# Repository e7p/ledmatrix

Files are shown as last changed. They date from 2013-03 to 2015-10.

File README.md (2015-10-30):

ledmatrix
=========

We got a couple of LED matrices in our Hackerspace /dev/tal in Wuppertal. Here there is held code and other useful things for them.

Important info: The Fusebit for "JTAG" MUST be deactivated for usage of PORT C, which is used by default for serial data!

How to build
------------

To build the Firmware, just enter the directory "main" and type `make`. For flashing the firmware `make flash` can be used, or the main.hex file can be flashed using an arbitrary AVR flashing tool.

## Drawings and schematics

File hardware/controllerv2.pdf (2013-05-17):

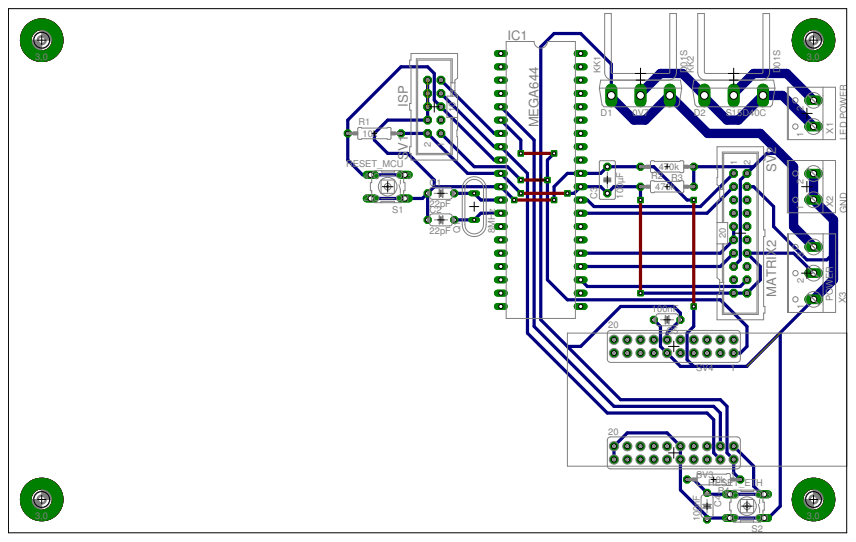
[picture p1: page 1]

10 21 12 20 1 20 1 20 1 2 1 2 1 2 3 2 1 4 3 2 1 4 3 IC1 Q1 C1 C2 C3 R1 SV1 SV2 X3 R2 R3 SV3 SV4 S1 S2 R4C4 C5 D1 D2 X1 X2 KK1 KK2 MEGA644 8MHz 22pF 22pF 100µF 10k ISP MATRIX2 POWER 470k R 470k ESET_MCU R1E0kSET_ETH 100nF 100nF 0V7 S15D40C LED POWER GND D01S D01S3,0 3,0 3,0 3,0

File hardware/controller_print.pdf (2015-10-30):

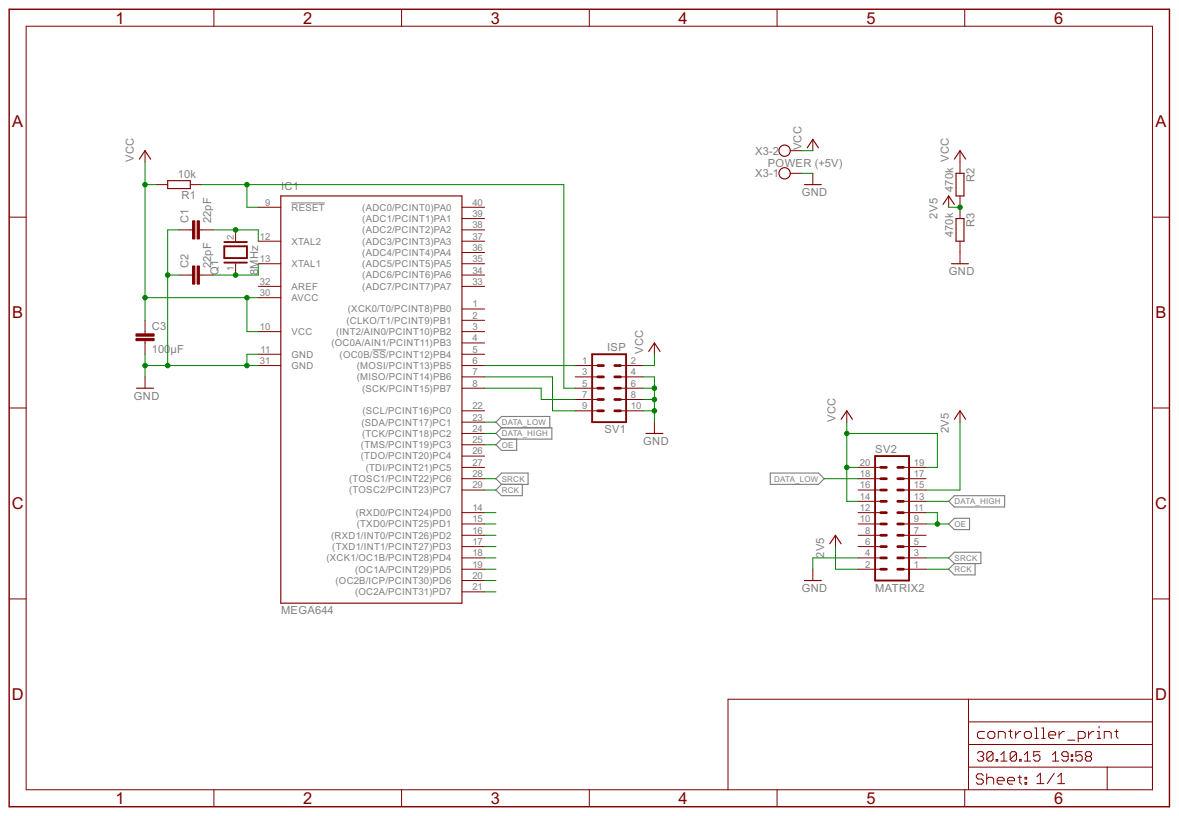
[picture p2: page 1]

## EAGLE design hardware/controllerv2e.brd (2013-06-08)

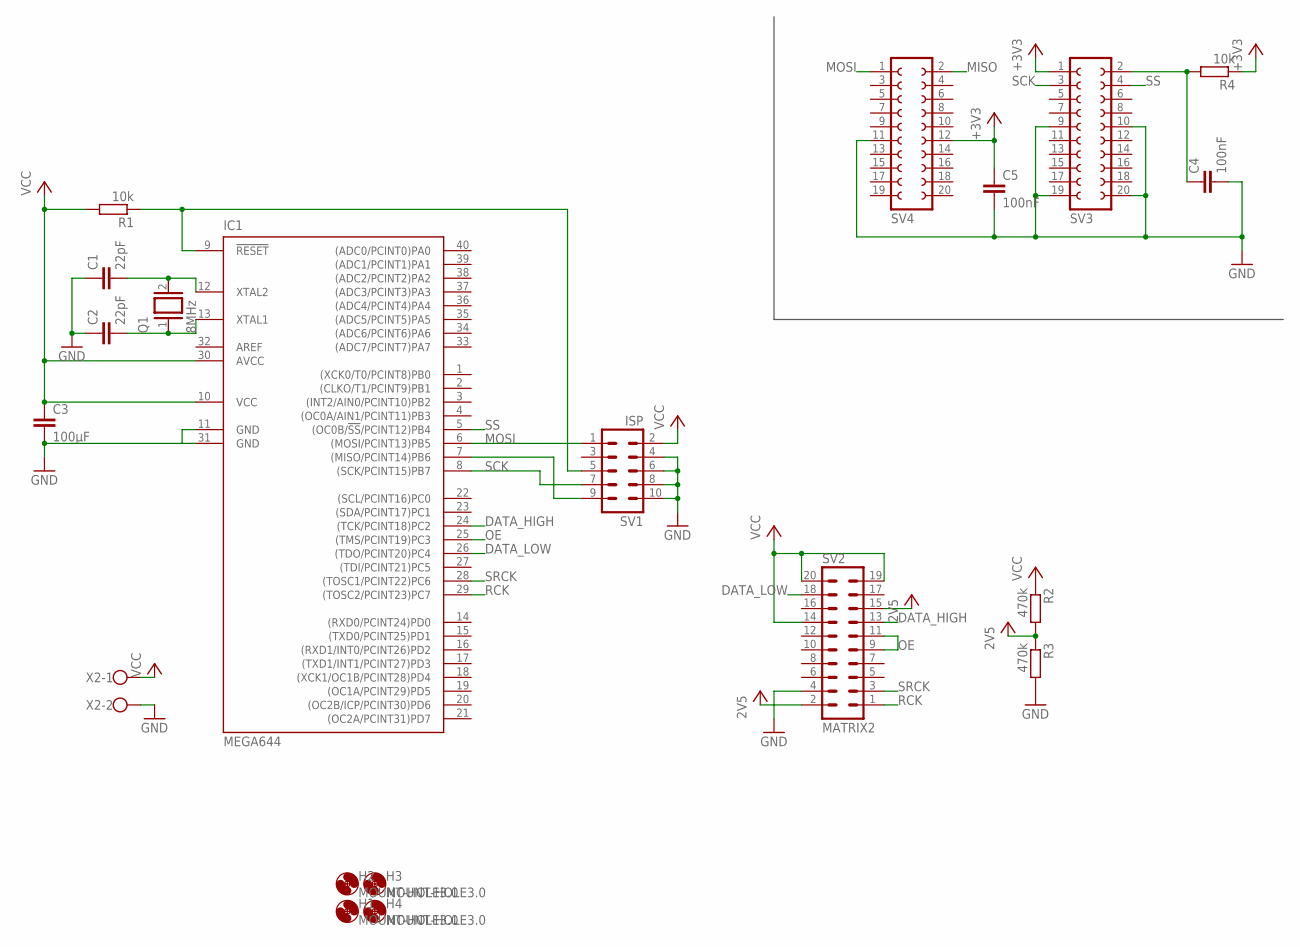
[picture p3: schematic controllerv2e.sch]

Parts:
C1, C2: 22pF; C050-024X044
C3: 100µF; C050-030X075
C4, C5: 100nF; C050-024X044
H1, H2, H3, H4: MOUNT-HOLE3.0; 3,0
IC1: MEGA644; DIL40
Q1: 8MHz; QS
R1, R4: 10k; 0207/10
R2, R3: 470k; 0207/10
SV1: ISP; ML10
SV2: MATRIX2; ML20
SV3, SV4: FE10-2
X2: GND; W237-102

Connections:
+3V3: C5.1, R2.2, R3.1, R4.1, SV2.2, SV2.15, SV3.1, SV4.12
AREF: IC1.32 (AREF)
DATA_HIGH: IC1.24 ((TCK/PCINT18)PC2), SV2.13
DATA_LOW: IC1.26 ((TDO/PCINT20)PC4), SV2.18
GND: C1.1, C2.1, C3.2, C4.2, C5.2, IC1.11 (GND), IC1.31 (GND), R3.2, SV1.4, SV1.6, SV1.8, SV1.10, SV2.4, SV3.9, SV3.10, SV3.19, SV3.20, SV4.11, X2.2
MISO: SV4.2
MOSI: IC1.6 ((MOSI/PCINT13)PB5), SV1.1, SV4.1
unnamed: C4.1, R4.2, SV3.2
unnamed: C2.2, IC1.13 (XTAL1), Q1.1
unnamed: C1.2, IC1.12 (XTAL2), Q1.2
unnamed: IC1.9 (!RESET), R1.1, SV1.5
unnamed: IC1.7 ((MISO/PCINT14)PB6), SV1.9
OE: IC1.25 ((TMS/PCINT19)PC3), SV2.9, SV2.11
RCK: IC1.29 ((TOSC2/PCINT23)PC7), SV2.1
SCK: IC1.8 ((SCK/PCINT15)PB7), SV1.7, SV3.3
SRCK: IC1.28 ((TOSC1/PCINT22)PC6), SV2.3
SS: IC1.5 ((OC0B/!SS!/PCINT12)PB4), SV3.4
VCC: C3.1, IC1.10 (VCC), IC1.30 (AVCC), R1.2, R2.1, SV1.2, SV2.14, SV2.19, SV2.20, X2.1

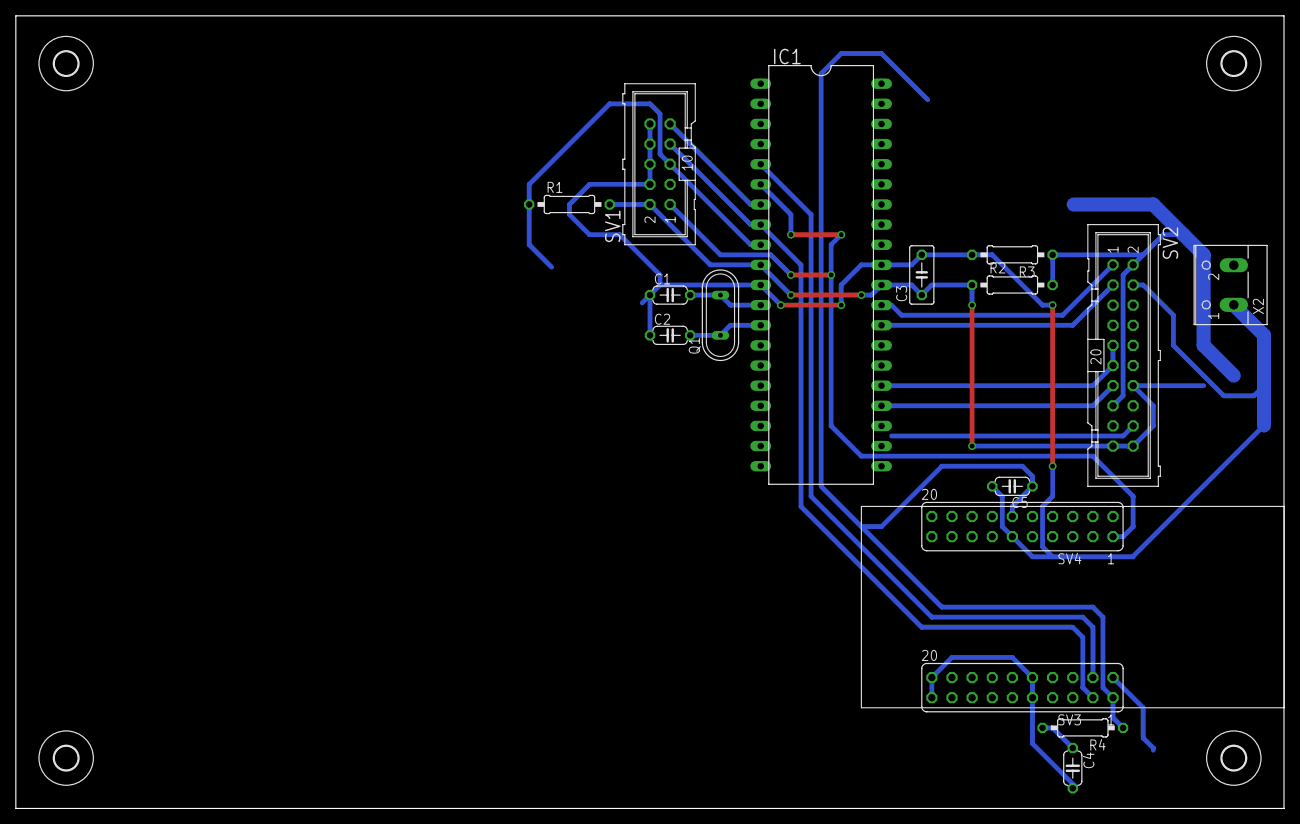
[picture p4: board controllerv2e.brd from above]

Board: 2 copper layers, 160.0 x 100.0 mm, 20 parts (0 on the bottom side), 16 nets.

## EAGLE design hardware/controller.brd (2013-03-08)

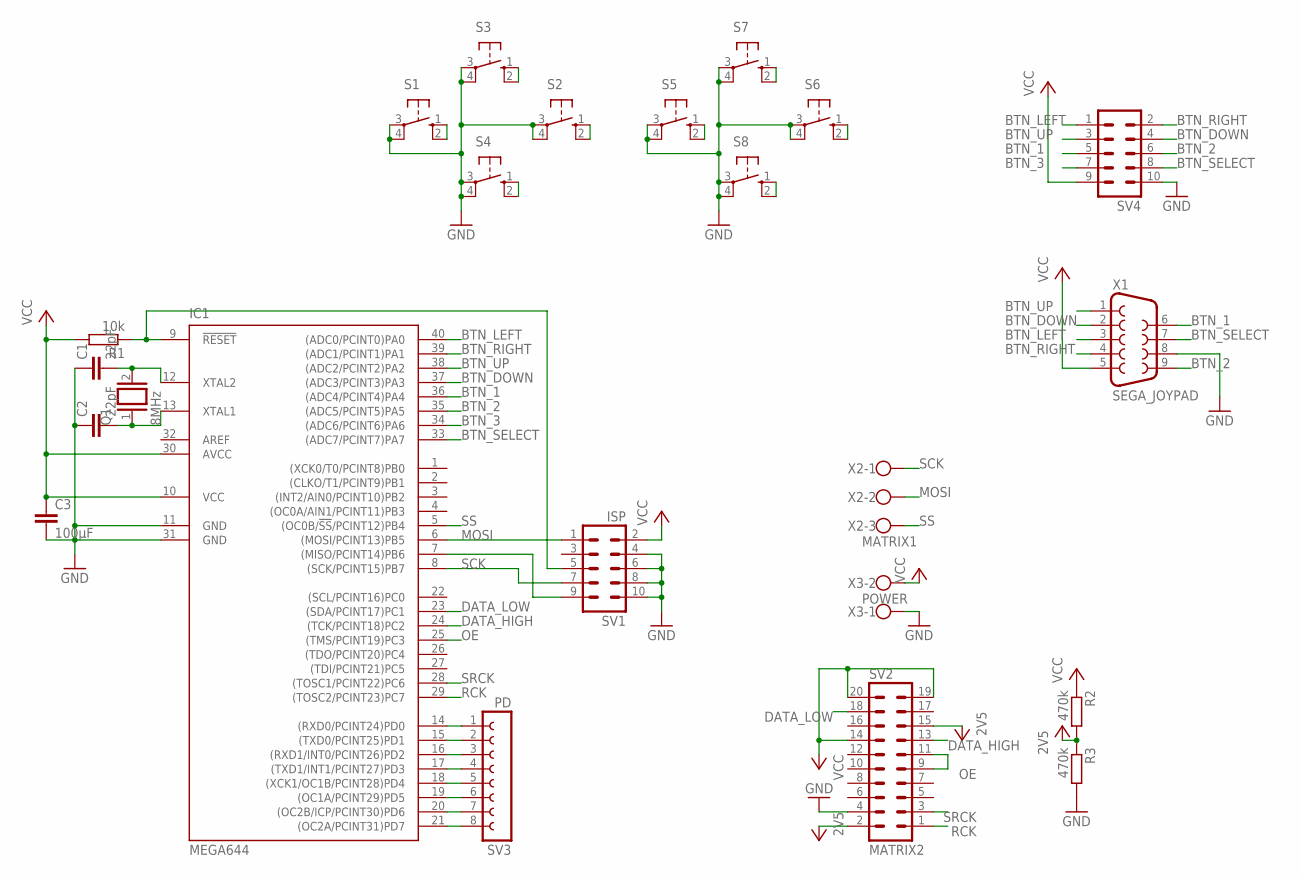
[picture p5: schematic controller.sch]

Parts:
C1, C2: 22pF; C050-024X044
C3: 100µF; C050-030X075
IC1: MEGA644; DIL40
Q1: 8MHz; QS
R1: 10k; 0207/10
R2, R3: 470k; 0207/10
S1, S5: 10-XX; B3F-10XX
S2, S3, S4, S6, S7, S8: 10-XX; B3F-10XX; MPN B3F-1000
SV1: ISP; ML10
SV2: MATRIX2; ML20
SV3: PD; FE08
SV4: ML10
X1: SEGA_JOYPAD; F09HP
X2: MATRIX1; W237-103
X3: POWER; W237-102

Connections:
+3V3: R2.2, R3.1, SV2.2, SV2.15
AREF: IC1.32 (AREF)
BTN_1: IC1.36 ((ADC4/PCINT4)PA4), S7.1 (S), S7.2 (S1), SV4.5, X1.6
BTN_2: IC1.35 ((ADC5/PCINT5)PA5), S5.1 (S), S5.2 (S1), SV4.6, X1.9
BTN_3: IC1.34 ((ADC6/PCINT6)PA6), S6.1 (S), S6.2 (S1), SV4.7
BTN_DOWN: IC1.37 ((ADC3/PCINT3)PA3), S4.1 (S), S4.2 (S1), SV4.4, X1.2
BTN_LEFT: IC1.40 ((ADC0/PCINT0)PA0), S1.1 (S), S1.2 (S1), SV4.1, X1.3
BTN_RIGHT: IC1.39 ((ADC1/PCINT1)PA1), S2.1 (S), S2.2 (S1), SV4.2, X1.4
BTN_SELECT: IC1.33 ((ADC7/PCINT7)PA7), S8.1 (S), S8.2 (S1), SV4.8, X1.7
BTN_UP: IC1.38 ((ADC2/PCINT2)PA2), S3.1 (S), S3.2 (S1), SV4.3, X1.1
DATA_HIGH: SV2.13
DATA_LOW: SV2.18
GND: C1.1, C2.1, C3.2, IC1.11 (GND), IC1.31 (GND), R3.2, S1.3, S1.4 (P1), S2.3, S2.4 (P1), S3.3, S3.4 (P1), S4.3, S4.4 (P1), S5.3, S5.4 (P1), S6.3, S6.4 (P1), S7.3, S7.4 (P1), S8.3, S8.4 (P1), SV1.4, SV1.6, SV1.8, SV1.10, SV2.4, SV4.10, X1.8, X3.1
MOSI: IC1.6 ((MOSI/PCINT13)PB5), SV1.1, X2.2
unnamed: C2.2, IC1.13 (XTAL1), Q1.1
unnamed: C1.2, IC1.12 (XTAL2), Q1.2
unnamed: IC1.9 (!RESET), R1.1, SV1.5
unnamed: IC1.14 ((RXD0/PCINT24)PD0), SV3.1
unnamed: IC1.7 ((MISO/PCINT14)PB6), SV1.9
unnamed: IC1.15 ((TXD0/PCINT25)PD1), SV3.2
unnamed: IC1.16 ((RXD1/INT0/PCINT26)PD2), SV3.3
unnamed: IC1.17 ((TXD1/INT1/PCINT27)PD3), SV3.4
unnamed: IC1.18 ((XCK1/OC1B/PCINT28)PD4), SV3.5
unnamed: IC1.19 ((OC1A/PCINT29)PD5), SV3.6
unnamed: IC1.20 ((OC2B/ICP/PCINT30)PD6), SV3.7
unnamed: IC1.21 ((OC2A/PCINT31)PD7), SV3.8
OE: SV2.9, SV2.11
RCK: IC1.29 ((TOSC2/PCINT23)PC7), SV2.1
SCK: IC1.8 ((SCK/PCINT15)PB7), SV1.7, X2.1
SRCK: IC1.28 ((TOSC1/PCINT22)PC6), SV2.3
SS: IC1.5 ((OC0B/!SS!/PCINT12)PB4), X2.3
VCC: C3.1, IC1.10 (VCC), IC1.30 (AVCC), R1.2, R2.1, SV1.2, SV2.14, SV2.19, SV2.20, SV4.9, X1.5, X3.2

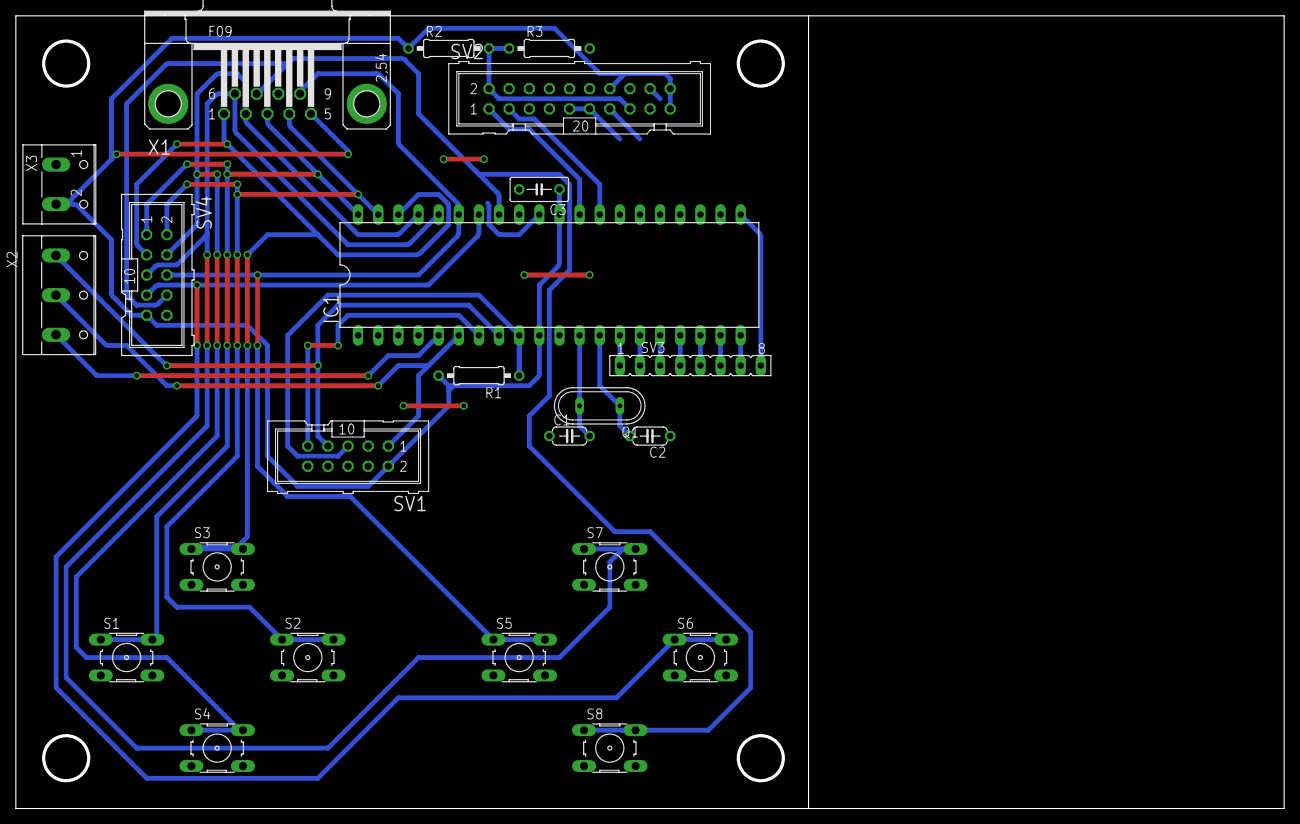
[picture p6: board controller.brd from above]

Board: 2 copper layers, 160.0 x 100.0 mm, 23 parts (0 on the bottom side), 29 nets.

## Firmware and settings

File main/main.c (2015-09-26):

#include <string.h>
#include <stdio.h>
#include <stdlib.h>
#include <avr/interrupt.h>
#include <avr/pgmspace.h>
#include "../lib/ledmatrix.h"
#include "../lib/ethernet.h"
#include "../net_time/time.h"

// Foo
#include "../net_time/timelib.h"
#include "../net_time/my_ethernet.h"

#define TELNET_CLOSED   0
#define TELNET_INACTIVE 1
#define TELNET_SHELL    2
#define TELNET_PROGRAM  3

extern void net_time_setup(void);
extern uint8_t net_time_loop(uint8_t);
extern void net_twitter_setup(void);
extern uint8_t net_twitter_loop(uint8_t);
extern uint8_t nyan_loop(uint8_t);
extern uint8_t augenkrebs_loop(uint8_t);
extern void message_setup(void);
extern uint8_t message_loop(uint8_t);
extern void message_unload(void);
extern void hotnews_setup(void);
extern uint8_t hotnews_loop(uint8_t);
extern void hotnews_unload(void);
extern uint8_t langertisch_loop(uint8_t);
extern uint8_t line_animation_loop(uint8_t);
extern uint8_t uptime_loop(uint8_t);
extern uint8_t pacman_loop(uint8_t);

struct modules {
  const char* name;
  void (*setup)(void);
  uint8_t (*loop)(uint8_t);
  void (*unload)(void);
};

#define MODULE_COUNT 9

static const struct modules module_list[MODULE_COUNT] = {
  { "net_time", &net_time_setup, &net_time_loop, NULL },
  //{ "net_twitter", &net_twitter_setup, &net_twitter_loop, NULL },
  { "nyan", NULL, &nyan_loop, NULL },
  { "augenkrebs", NULL, &augenkrebs_loop, NULL },
  { "message", &message_setup, &message_loop, &message_unload },
  { "hotnews", &hotnews_setup, &hotnews_loop, &hotnews_unload },
  { "langertisch", NULL, &langertisch_loop, NULL },
  { "line_animation", NULL, &line_animation_loop, NULL },
  { "uptime", NULL, &uptime_loop, NULL },
  { "pacman", NULL, &pacman_loop, NULL }
};

struct command {
  const char* name;
  void (*run)(char*);
};

const char welcome_message[] PROGMEM = "LED Matrix v0.1 - Built " __DATE__ " " __TIME__ "\r\n";

#define MAX_MODULES 16
#define MAX_COMMANDS 4

static uint8_t loaded_modules[MAX_MODULES];
static struct command* commands[MAX_COMMANDS];
static uint8_t loaded_modules_count = 0;
static uint8_t active_module = 0, rot_module = 0, last_module = 0;

static uint8_t tick = 0;
uint32_t uptime = 0;

uint8_t addModule(char* module) {
  for(int i = 0; i < MODULE_COUNT; i++) {
    if(strcmp(module_list[i].name, module) == 0) {
      for(int j = 0; j < MAX_MODULES; j++) {
        if(loaded_modules[j] == i) {
          // module already loaded
          return 3;
        }
      }
      for(int j = 0; j < MAX_MODULES; j++) {
        if(loaded_modules[j] == 255) {
          loaded_modules[j] = i;
          if(module_list[i].setup != NULL) {
            module_list[i].setup();
          }
          loaded_modules_count++;
          // module loaded
          return 0;
        }
      }
      // already MAX_MODULES loaded
      return 1;
    }
  }
  // module not found
  return 2;
}

uint8_t addCommand(const char* name, void (*callback)(char*)) {
  for(int i = 0; i < MAX_COMMANDS; i++) {
    if(commands[i] == 0)
      continue;
    if(strcmp(commands[i]->name, name) == 0)
      return 0;
  }
  for(int i = 0; i < MAX_COMMANDS; i++) {
    if(commands[i] == 0) {
      struct command *cmd = malloc(sizeof(struct command));
      cmd->name = name;
      cmd->run = callback;
      commands[i] = cmd;
      return 1;
    }
  }
}

uint8_t delModule(char* module) {
  for(int i = 0; i < MAX_MODULES; i++) {
    if(strcmp(module_list[loaded_modules[i]].name, module) == 0) {
      // module unloaded
      if(module_list[loaded_modules[i]].unload != NULL) {
        module_list[loaded_modules[i]].unload();
      }
      loaded_modules[i] = 255;
      loaded_modules_count--;
      return 0;
    }
  }
  // module not found
  return 2;
}

uint8_t delCommand(const char* name) {
  for(int i = 0; i < MAX_COMMANDS; i++) {
    if(commands[i] == 0)
      continue;
    if(strcmp(commands[i]->name, name) == 0) {
      free(commands[i]);
      commands[i] = 0;
      return 1;
    }
  }
  return 0;
}

void setup() {
  ledmatrix_setup();
  ethernet_setup();
  
  for(int i = 0; i < MAX_MODULES; i++) {
    loaded_modules[i] = 255;
  }
  
  // Initialize Timers
  // 16-bit Timer 1 at 1s
  TCCR1B = (1<<CS12) | (1<<WGM12); // Prescaler 256
  OCR1A = 31250-1;
  
  // Interrupts
  TIMSK1 |= (1<<OCIE1A);
  sei();

  // TEMP static bootloader
  addModule("net_time");
  //net_time_loop(0);
  addModule("nyan");
  //addModule("hotnews");
}

uint8_t telnet_status = 0;
uint8_t buf[256];
uint8_t tmp[256];

void loop() {
  /* Clock */
  while(tick > 0) {
    tick--;
    uptime++;
  }
  
  /* Telnet Loop */
  uint8_t status = GetStatus(3);
  switch(status) {
    case W5100_SKT_SR_CLOSED:
    telnet_status = TELNET_CLOSED;
    OpenSocket(3, W5100_SKT_MR_TCP, 23);
    break;
    
    case W5100_SKT_SR_INIT:
    Listen(3);
    break;

    case W5100_SKT_SR_ESTABLISHED:
    if(telnet_status == TELNET_CLOSED) {
      strcpy_P((char *)buf, welcome_message);
      Send(3, buf, strlen((char *)buf));
      telnet_status = TELNET_INACTIVE;
    }
    break;

    case W5100_SKT_SR_FIN_WAIT:
    case W5100_SKT_SR_CLOSING:
    case W5100_SKT_SR_TIME_WAIT:
    case W5100_SKT_SR_CLOSE_WAIT:
    case W5100_SKT_SR_LAST_ACK:
    CloseSocket(3);
    telnet_status = TELNET_CLOSED;
    break;
  }
  unsigned int rsize;
  switch(telnet_status) {
    case TELNET_INACTIVE:
    Send(3, "$ ", 2);
    telnet_status = TELNET_SHELL;
    //break;
    
    case TELNET_SHELL:
    // Check if data received
    rsize = ReceivedSize(3); // find out how many bytes
    if(rsize > 0) {
      if(Receive(3, buf, rsize) != W5100_OK) break;
      if(buf[0] & 0x80) break;
      char* arg = strtok(buf, " \r\n");
      if(strcmp(arg, "exit") == 0) {
        DisconnectSocket(3);
      } else if(strcmp(arg, "actmod") == 0) {
        arg = strtok(NULL, " \r\n");
        for(int i = 0; i < MAX_MODULES; i++) {
          if(loaded_modules[i] < 255 &&
            strcmp(module_list[loaded_modules[i]].name, arg) == 0) {
            active_module = loaded_modules[i];
            strcpy(tmp, arg);
            sprintf(buf, "Active Module set to: %s\r\n", tmp);
            SendString(3, buf);
            break;
          }
        }
      } else if(strcmp(arg, "modprobe") == 0) {
        arg = strtok(NULL, " \r\n");
        strcpy(tmp, arg);
        if(addModule(tmp) == 0) {
          sprintf(buf, "Module %s loaded\r\n", tmp);
        }
        SendString(3, buf);
      } else if(strcmp(arg, "lsmod") == 0) {
        tmp[0] = '\0';
        for(int i = 0; i < MAX_MODULES; i++) {
          if(loaded_modules[i] < 255) {
            strcat(tmp, module_list[loaded_modules[i]].name);
            strcat(tmp, ", ");
          }
        }
        tmp[strlen(tmp)-2] = '\0';
        sprintf(buf, "Modules: %s\r\n", tmp);
        SendString(3, buf);
      } else if(strcmp(arg, "rmmod") == 0) {
        arg = strtok(NULL, " \r\n");
        strcpy(tmp, arg);
        if(delModule(tmp) == 0) {
          sprintf(buf, "Module %s unloaded\r\n", tmp);
        }
        SendString(3, buf);
      } else if(strcmp(arg, "getmod") == 0) {
        sprintf(buf, "Rotated module: %d, Current module: %s(%d)\r\n", rot_module, module_list[active_module].name, active_module);
        SendString(3, buf);
      } else if(strcmp(arg, "uptime") == 0) {
        sprintf(buf, "Uptime: %d seconds\r\n", uptime);
        SendString(3, buf);
      } else if(strcmp(arg, "help") == 0 || strcmp(arg, "?") == 0) {
        SendString(3, "Defined functions:\r\n  ?, actmod, exit, getmod, help, lsmod, modprobe, rmmod, uptime\r\n");
        strcpy(tmp, "Module commands:\r\n  ");
        for(int i = 0; i < MAX_COMMANDS; i++) {
          if(commands[i] != 0) {
            strcat(tmp, commands[i]->name);
            strcat(tmp, ", ");
          }
        }
        uint8_t c = strlen(tmp);
        tmp[c-2] = '\r';
        tmp[c-1] = '\n';
        SendString(3, tmp);
      } else {
        for(int i = 0; i < MAX_COMMANDS; i++) {
          if(commands[i] != 0 && strcmp(commands[i]->name, arg) == 0) {
            commands[i]->run(strtok(buf+strlen(arg)+1, "\r\n"));
            goto finish;
          }
        }
        SendString(3, "Unknown command\r\n");
      }
finish: telnet_status = TELNET_INACTIVE;
    }
    break;
    
    case TELNET_PROGRAM:
    // Do nothing, program is running
    break;
    
    case TELNET_CLOSED:
    // Do nothing, telnet is closed
    break;
  }

  /* Module Loop functions */
  last_module = active_module;
  for(int i = 0; i < MAX_MODULES; i++) {
    if(loaded_modules[i] < 255) {
      if(loaded_modules[i] == active_module) {
        if(module_list[active_module].loop(last_module == active_module ? 2 : 1) > 0) {
          // rotate active module
          if(rot_module == active_module && loaded_modules_count > 1) {
            do {
              rot_module++;
              if(rot_module == MAX_MODULES) rot_module = 0;
            } while(loaded_modules[rot_module] == 255);
          }
          active_module = loaded_modules[rot_module];
        }
      } else {
        if(module_list[loaded_modules[i]].loop(0) == 255) {
          // set active module to this
          active_module = loaded_modules[i];
        }
      }
    }
  }
  
  //TEMP:
  setPixel(0,0,telnet_status == TELNET_CLOSED);
  setPixel(0,1,telnet_status == TELNET_INACTIVE);
  setPixel(0,2,telnet_status == TELNET_SHELL);
  setPixel(0,3,telnet_status == TELNET_PROGRAM);
  
  shiftPixelData();
}

ISR(TIMER1_COMPA_vect) {
  // Clock tick
  tick++;
}

int main() {
  setup();
  while(1) loop();
}

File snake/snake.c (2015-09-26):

/* Snake Game for LED-Matrix "blinkofant"
 * Code by Endres, based on code by wizard23 */
#define F_CPU 8000000UL
#include <avr/io.h>
#include <avr/interrupt.h>
#include <util/delay.h>
#include <stdbool.h>

#define CLEAR_PANEL_PIN PB4
// atmega pin #5 <-> panel pin #10

#define DATA_PIN PB5
// atmega pin #6 <-> panel pin #8

#define CLOCK_PIN PB7
// atmega pin #8 <-> panel pin #4 

#define LEFT_PIN PA0
#define RIGHT_PIN PA1

#define PANELS 1
#define PANELDATA_SIZE (10*PANELS)

#define DIR_RIGHT 0
#define DIR_BOTTOM 1
#define DIR_LEFT 2
#define DIR_TOP 3

uint8_t panelData[PANELDATA_SIZE];

uint8_t snakePos[PANELS*8*9][2];
uint8_t foodPos[2];
uint8_t snakeLength;
uint8_t snakeDir;

uint8_t buttonValue;
uint8_t buttonStatus;

uint8_t gameTick;

uint16_t random;

uint8_t cnt;
uint8_t bl;

void clear() {
  for(uint8_t i = 0; i < PANELDATA_SIZE; i++) {
    panelData[i] = 0;
  }
}

void setPixel(uint8_t x, uint8_t y, uint8_t value) {
  uint8_t index = (y+1) + x*10; // y+1 because 1st bit controls blinking
  uint8_t byteNum = index >> 3; // division by 8
  uint8_t bitNum = index & 0x7; // remainder at division by 8

  if (value)
    panelData[byteNum] |= 1 << bitNum;
  else
    panelData[byteNum] &= ~(1 << bitNum);
}

uint8_t getPixel(int x, int y) {
  uint8_t index = (y+1) + x*10; // See above
  uint8_t byteNum = index >> 3;
  uint8_t bitNum = index & 0x7;
  return panelData[index >> 3] & (1 << index & 0x7);
}

void togglePixel(int x, int y) {
  uint8_t index = (y+1) + x*10; // See above
  uint8_t byteNum = index >> 3;
  uint8_t bitNum = index & 0x7;
  panelData[byteNum] ^= 1 << bitNum;
}

void screen_off() {
  PORTB &= ~(1<<CLEAR_PANEL_PIN);
}

void screen_on() {
  PORTB |= (1<<CLEAR_PANEL_PIN);
}

bool inSnake(uint8_t x, uint8_t y) {
  for(uint8_t i = 0; i < snakeLength; i++) {
    if(snakePos[i][0] == x && snakePos[i][1] == y)
      return true;
  }
  return false;
}

void newFood() {
  do {
    foodPos[0] = random % 8;
    foodPos[1] = random % 9;
    random++;
  } while(inSnake(foodPos[0], foodPos[1]));
}

void shiftPixelData() {
  screen_off(); // needed?
  
  for(int i = 0; i < PANELDATA_SIZE; i++) {
    uint8_t value = panelData[i];
    
    SPDR = panelData[i];
    while(!(SPSR & (1<<SPIF)));
  }
  
  screen_on(); // needed?
}

#define SPI_MODE_MASK 0x0C  // CPOL = bit 3, CPHA = bit 2 on SPCR
#define SPI_MODE0 0x00
#define SPI_CLOCK_MASK 0x03  // SPR1 = bit 1, SPR0 = bit 0 on SPCR
#define SPI_CLOCK_DIV128 0x03
#define SPI_2XCLOCK_MASK 0x01  // SPI2X = bit 0 on SPSR

void setup() {
  // Initialize serial connection to matrix
  PORTB |= (1<<CLEAR_PANEL_PIN);
  DDRB |= (1<<CLEAR_PANEL_PIN)|(1<<DATA_PIN)|(1<<CLOCK_PIN);
  SPCR |= _BV(MSTR);
  SPCR |= _BV(SPE);
  SPCR |= _BV(DORD);
  SPCR = (SPCR & ~SPI_MODE_MASK) | SPI_MODE0;
  SPCR = (SPCR & ~SPI_CLOCK_MASK) | (SPI_CLOCK_DIV128 & SPI_CLOCK_MASK);
  SPSR = (SPSR & ~SPI_2XCLOCK_MASK) |
    ((SPI_CLOCK_DIV128 >> 2) & SPI_2XCLOCK_MASK);

  // Initialize Timers
  // 8-bit Timer 0 at 8.16ms
  TCCR0B |= (1<<CS02); // Prescaler 256
  // 16-bit Timer 1 at 524.28ms
  TCCR1B = (1<<CS00) | (1<<CS01); // Prescaler 64

  // Interrupts
  TIMSK0 |= (1<<TOIE0);
  TIMSK1 |= (1<<TOIE1);
  sei();

  // Initialize Snake
  snakeLength = 5;
  snakeDir = DIR_RIGHT;

  DDRA &= ~((1<<LEFT_PIN)|(1<<RIGHT_PIN));
  PORTA |= (1<<LEFT_PIN)|(1<<RIGHT_PIN);

  for(int x = 0; x < 8*PANELS; x++) {
    for(int y = 0; y < 9; y++) {
      if(y < 1 && x < snakeLength) {
        snakePos[x][0] = x;
        setPixel(x, y, 1);
      }
    }
  }
  
  newFood();
}

void shiftSnake() {
  for(int i = 0; i <= snakeLength; i++) {
    snakePos[i][0] = snakePos[i+1][0];
    snakePos[i][1] = snakePos[i+1][1];
  }
}

void snakeLeft() {
  snakeDir = (snakeDir + 3) % 4;
}

void snakeRight() {
  snakeDir = (snakeDir + 1) % 4;
}

void loop() {
  if(gameTick > 0) {
    if(buttonValue & (1<<LEFT_PIN)) snakeLeft();
    if(buttonValue & (1<<RIGHT_PIN)) snakeRight();
    buttonValue &= ~((1<<LEFT_PIN) | (1<<RIGHT_PIN));

    snakePos[snakeLength][0] = snakePos[snakeLength-1][0];
    snakePos[snakeLength][1] = snakePos[snakeLength-1][1];
    if(snakeDir == DIR_LEFT) {
      snakePos[snakeLength][0] = snakePos[snakeLength-1][0] - 1;
      if(snakePos[snakeLength][0] == 255) snakePos[snakeLength][0] = 7;
    } else if(snakeDir == DIR_RIGHT) {
      snakePos[snakeLength][0] = snakePos[snakeLength-1][0] + 1;
      if(snakePos[snakeLength][0] >= 8) snakePos[snakeLength][0] = 0;
    } else if(snakeDir == DIR_TOP) {
      snakePos[snakeLength][1] = snakePos[snakeLength-1][1] - 1;
      if(snakePos[snakeLength][1] == 255) snakePos[snakeLength][1] = 8;
    } else { // BOTTOM
      snakePos[snakeLength][1] = snakePos[snakeLength-1][1] + 1;
      if(snakePos[snakeLength][1] >= 9) snakePos[snakeLength][1] = 0;
    }
    
    if(snakePos[snakeLength][0] == foodPos[0] &&
      snakePos[snakeLength][1] == foodPos[1]) {
      snakeLength++;
      newFood();
    } else if(getPixel(snakePos[snakeLength][0], snakePos[snakeLength][1])) {
      // Game over
      //setPixel(0, 0, 1);
    } else {
      //setPixel(snakePos[0][0], snakePos[0][1], 0);
      //setPixel(snakePos[snakeLength][0], snakePos[snakeLength][1], 1);
      shiftSnake();
    }
    // draw Snake
    clear();
    for(uint8_t i = 0; i < snakeLength; i++) {
      setPixel(snakePos[i][0], snakePos[i][1], 1);
    }
    shiftPixelData();
    
    gameTick--;
  }
  if(cnt == 3) {
    setPixel(foodPos[0], foodPos[1], bl % 2);
    bl++;
    shiftPixelData();
    cnt = 0;
  }
  random++;
}

ISR(TIMER0_OVF_vect) {
  // Button timer (including simple debounce)
  buttonValue |= PINA & ~buttonStatus | buttonValue;
  buttonStatus = PINA | buttonStatus & buttonValue;
  cnt++;
}

ISR(TIMER1_OVF_vect) {
  // Game timer
  gameTick++;
}

int main() {
  setup();
  while(1) loop();
}

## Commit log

2013-02-03 Adding timers and status LEDs. The Input does not work as expected
2013-02-03 Supporting Assembler option
2013-02-08 Hardware and some fixes, but also more inefficient snake drawing
    [controller.brd, controller.sch]
2013-02-16 Updated Hardware
    [controller.brd, controller.sch]
2013-03-08 Big text marquee and slight hardware modification
    [controller.brd, controller.sch]
2013-03-20 Adding avrsim ledmatrix board.
2013-05-17 Update to current state of development
2013-05-17 New files to current state of development
    [controllerv2.brd, controllerv2.sch]
2013-06-08 Tetris fixes
    [controllerv2e.brd, controllerv2e.sch]
2013-06-22 Fixing font library, working on network
    [marquee.c, test.c]
2013-07-13 Test 2 for LEDMatrix 2
2015-10-30 added license, print version of the hardware, updated readme and modified NTP IP
    [controller_print.sch]
